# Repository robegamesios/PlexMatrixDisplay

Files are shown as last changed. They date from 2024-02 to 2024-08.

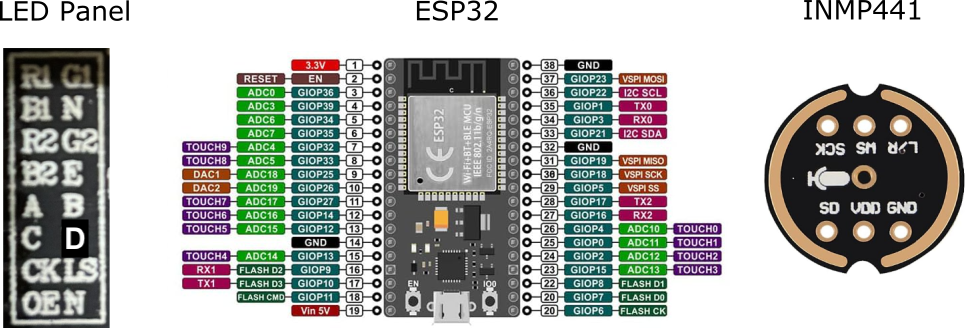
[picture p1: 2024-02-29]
docs/tuneframePinout.png

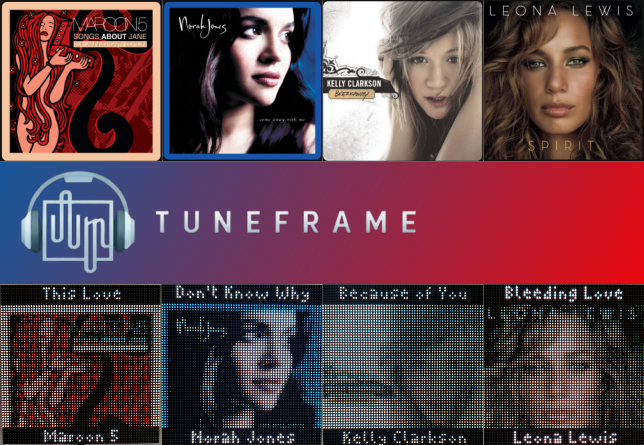
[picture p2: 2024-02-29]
docs/tuneframe.png

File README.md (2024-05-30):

# TUNEFRAME

_**TuneFrame is an ESP32-powered LED matrix panel that serves as a dynamic music visualizer. It syncs captivating LED light patterns with your favorite tunes and displays album art from Spotify and PlexAmp, enhancing your listening experience with vibrant visuals. It also serves as a weather clock station providing current weather information, and as an Animated GIF display to play your favorite GIF art.**_

tuneframe

sddefault



# Video tutorials: 

https://youtu.be/m5aLhCCSwWE?si=qLfko10hiLxpDJDM

https://youtu.be/RzFt6x_XNsM?si=SkvgdLdjnOrtg5Ka

# Hardware

The project will cost less than $30 to build. You can get any of these items somewhere else, but I found Aliexpress to be the cheapest vendor.

1. P3 64 x 64 LED Matrix Panel ($15) - https://www.aliexpress.us/item/3256803863694770.html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
2. INMP441 Omnidirectional Microphone module ($1) - https://www.aliexpress.us/item/3256805923157007.html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
3. ESP32 Wroom 32 Development Board ($3) - https://www.aliexpress.us/item/3256806034074322.html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
4. Dupont cables ($2) - https://www.aliexpress.us/item/3256805941164824.html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
5. 5V 2A power adapter (higher current the better) ($5) - https://www.aliexpress.us/item/3256802434250774.html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
   
# Pinouts

Pinout information can be found here: https://github.com/mrfaptastic/ESP32-HUB75-MatrixPanel-DMA. Below is the connection between the panel and the ESP32. Use female-to-female dupont cables to connect them together.

tuneframePinout

# LED Panel => ESP32

R1 => PIN 25

G1 => PIN 26

B1 => PIN 27

N = GND => Connect to common ground (no. 14 on ESP32 diagram)

R2 => PIN 14

G2 => PIN 12

B2 => PIN 13

E => PIN 18

A => PIN 23

B => PIN 19

C => PIN 5

D => PIN 17

CK => PIN 16

LS (also known as LAT) => 4

OE => PIN 15

N = GND => Connect to common ground (no. 14 on ESP32 diagram)

# INMP441 => ESP32

SD => PIN 32

VDD => 3.3V (no. 1 on ESP32 diagram)

GND => Connect to common ground (no. 14 on ESP32 diagram)

L/R => Connect to common ground (no. 14 on ESP32 diagram)

WS => PIN 2

SCK => PIN 33

# Using a single Power Supply

CAUTION: DO NOT CONNECT THE Vin 5V Pin to the power supply and also connect a micro-usb cable to your computer at the same time, this will fry your ESP32. If you're uploading code using the micro-usb cable, make sure the Vin 5V Pin is not connected to anything.

If you want to use a single power supply for both the LED Panel and the ESP32, you can daisy chain from the 5V power supply and connect the positive (+) terminal to the Vin 5V Pin (no. 19 in the diagram) of the ESP32.

# Software:

# Using Over the Air Update:

1. Download otaDefaultUpdate.ino from here: https://github.com/robegamesios/TUNEFRAME/blob/f9670607f996004907c58c464b867fd6b849f5fa/otaDefaultUpdate/otaDefaultUpdate.ino
2. Download the TuneFrameFirmware.bin from here: https://github.com/robegamesios/TUNEFRAME/blob/f9670607f996004907c58c464b867fd6b849f5fa/binFiles/TuneFrameFirmware.bin
3. Open otaDefaultUpdate.ino, then edit lines 8 and 9 to use your 2.4Ghz wifi credentials.
4. Upload it to your ESP32.
5. Open the Arduino IDE Serial Monitor (top right icon that looks like a Magnifying glass). Notice the wifi IP address.
6. Open your web browser and access the IP address.
7. Leave the User ID and Password blank, and click Login.
8. Choose the file you downloaded from step 2, then click Update.
9. Wait for the upload to finish, it should restart the ESP32 and you see TUNEFRAME at startup.

# Using Visual Studio Code:

1. Fork the TUNEFRAME repo or download the zip file.
2. Import the project in Visual Studio Code using Platform.io. (I'm assuming you are familiar on how to import a platform.io project).

# Get your PlexAmp Auth token:

1. Login to your Plex Media Server using Chrome.
2. Go to your music library, then right click on the page and click "Inspect".
3. Go to the "elements" tab.
4. Search for X-Plex-Token key. Your Auth token will be the characters squeezed between 2 X-Plex-Token keys.
   ```
   X-Plex-Token%3DThisIsYourAuthToken&X-Plex-Token

# Fetching Spotify Refresh Token via Curl command:

You can also get your spotify refresh token using this website: https://robegamesios.github.io/spotify-refresh-token/

1. Download `get-spotify-auth-code.js` from here: https://github.com/robegamesios/TUNEFRAME/blob/926691ebbc9ba7eea4be319e6fc88895b16115f2/misc/get-spotify-auth-code.js
2. Open `get-spotify-auth-code.js` and change lines 8 and 9 to use your Spotify Client ID and Client Secret. Then run it to get the authorization code.
3. Next run this CURL command to get the access token and refresh token:
   ```
   curl -d client_id=[client_id] -d client_secret=[client_secret] -d grant_type=authorization_code -d code=[auth code from step 2] -d redirect_uri=http%3A%2F%2F[esp32 ip address]%2Fcallback/ https://accounts.spotify.com/api/token

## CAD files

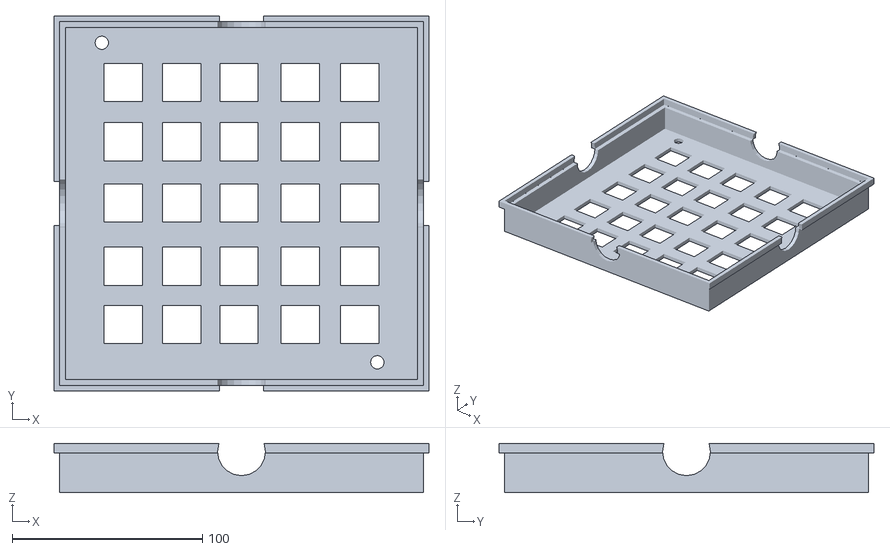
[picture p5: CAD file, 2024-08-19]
stlFiles/p3PanelCase.stl
197.0 x 197.0 x 26.0

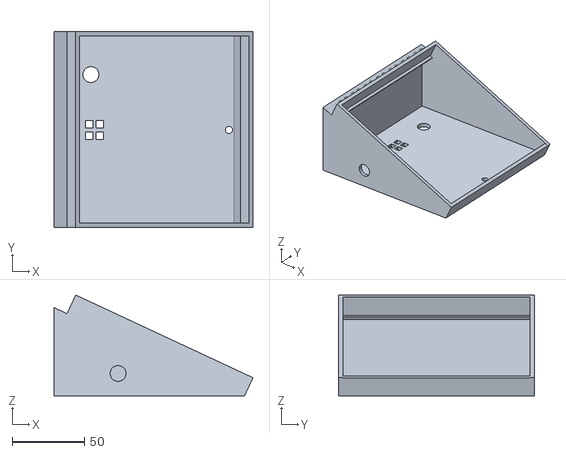
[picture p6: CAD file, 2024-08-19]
stlFiles/p2PanelCase.stl
137.3 x 135.0 x 69.6

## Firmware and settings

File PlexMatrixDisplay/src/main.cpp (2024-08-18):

#define WEATHER_STATION_THEME 90
#define AUDIO_VISUALIZER_THEME 100
#define PLEX_ALBUM_ART_THEME 200
#define SPOTIFY_ALBUM_ART_THEME 201
#define ANIMATED_GIF_THEME 210

// #define DEBUG // UnComment to see debug prints

#define ENABLE_MATRIX_DISPLAY // Comment this to disable matrix display (for debugging purposes when no display is connected)

#include "MatrixDisplay.h"
#include "TFWifiManager.h"
#include "TFNetworking.h"
#include "WeatherClock.h"
#include "PlexAmpLogic.h"
#include "SpotifyLogic.h"
#include "AnimatedGifLogic.h"
#include "jRead.h"

// ******************************************* BEGIN GLOBAL VARS AND COMMON FUNC ******************************
#pragma region GLOBAL_VARS_AND_UTILS

uint8_t selectedTheme;
uint8_t currentlyRunningTheme;
uint8_t panelBrightness;

String scrollingText = "";
String lowerScrollingText = "";
String lastAlbumArtURL = ""; // Variable to store the last downloaded album art URL
bool musicPlayerActive = false;

struct ThemeInfo
{
  String title;
  String filename;

  ThemeInfo(String name, String file)
      : title(name), filename(file) {}
};

ThemeInfo getThemeInfo()
{
  if (selectedTheme == WEATHER_STATION_THEME)
  {
    return ThemeInfo("WEATHER CLOCK", "weatherclock_FW");
  }
  else if (selectedTheme == AUDIO_VISUALIZER_THEME)
  {
    return ThemeInfo("MUSIC VISUALIZER", "musicVisualizer_FW");
  }
  else if (selectedTheme == PLEX_ALBUM_ART_THEME)
  {
    return ThemeInfo("PlEXAMP ART", "plexArt_FW");
  }
  else if (selectedTheme == SPOTIFY_ALBUM_ART_THEME)
  {
    return ThemeInfo("SPOTIFY ART", "spotifyArt_FW");
  }
  else if (selectedTheme == ANIMATED_GIF_THEME)
  {
    return ThemeInfo("ANIMATED GIF ART", "animatedGifArt_FW");
  }

  return ThemeInfo("UNKNOWN THEME", "");
}

void resetAlbumArtVariables()
{
  scrollingText = "";
  lowerScrollingText = "";
  lastAlbumArtURL = "";
}

void deleteAlbumArt()
{
  if (SPIFFS.exists(ALBUM_ART) == true)
  {
    Serial.println("Removing existing image");
    SPIFFS.remove(ALBUM_ART);
  }
}

void displayNoTrackPlaying()
{
#ifdef DEBUG
  Serial.println("No track is currently playing.");
#endif

  musicPlayerActive = false;
  resetAlbumArtVariables();
  clearScreen();
  printCenter("NO TRACK IS", 20, myPURPLE);
  printCenter("CURRENTLY", 30, myPURPLE);
  printCenter("PLAYING", 40, myPURPLE);
}

void displayCheckWeatherCredentials()
{
#ifdef DEBUG
  Serial.println("Check Weather credentials");
#endif

  resetAlbumArtVariables();
  clearScreen();
  printCenter("CHECK WEATHER", 25, myRED);
  printCenter("CREDENTIALS", 35, myRED);
}

void displayCheckPlexAmpCredentials()
{
#ifdef DEBUG
  Serial.println("Check PlexAmp credentials");
#endif

  resetAlbumArtVariables();
  clearScreen();
  printCenter("CHECK PLEXAMP", 25, myRED);
  printCenter("CREDENTIALS", 35, myRED);
}

void displayCheckSpotifyCredentials()
{
#ifdef DEBUG
  Serial.println("Check Spotify credentials");
#endif

  resetAlbumArtVariables();
  clearScreen();
  printCenter("CHECK SPOTIFY", 25, myRED);
  printCenter("CREDENTIALS", 35, myRED);
}

void displayMusicPaused()
{
  String musicPaused = "Music Paused";
  if (lowerScrollingText != musicPaused)
  {
    lowerScrollingText = musicPaused;
  }
}

void displayFailureReloadGifArt()
{
#ifdef DEBUG
  Serial.println("cannot open gif file");
#endif

  printCenter("FAILURE..", 15, myRED);
  printCenter("TRY LOADING", 25, myRED);
  printCenter("GIF ART AGAIN", 35, myRED);
  printCenter("FROM BROWSER", 45, myRED);
}

void restartDevice()
{
  clearScreen();
  printCenter("RESTARTING..", 30);
  delay(1000);
  ESP.restart();
}

void resetWifi()
{
  printCenter("RESETTING WiFi..", 30);
  wifiManager.resetSettings();
}

#pragma endregion
// ******************************************* END GLOBAL VARS AND COMMON FUNC ********************************

// ******************************************* BEGIN PREFERENCES **********************************************
#pragma region PREFERENCES

#include <Preferences.h>

Preferences preferences;
const char *PREF_SELECTED_THEME = "selectedTheme";
const char *PREF_AV_PATTERN = "avPattern";
const char *PREF_GIF_ART_URL = "gifArtUrl";
const char *PREF_WEATHER_STATION_CREDENTIALS = "weatherStationCredentials";
const char *PREF_PLEX_CREDENTIALS = "plexCredentials";
const char *PREF_SPOTIFY_CREDENTIALS = "spotifyCredentials";
const char *PREF_DISPLAY_GIF_TIME_AND_WEATHER = "displayGifTimeAndWeather";
const char *PREF_PANEL_BRIGHTNESS = "panelBrightness";

void savePreferences()
{
  preferences.putUInt(PREF_SELECTED_THEME, selectedTheme);
  preferences.putUInt(PREF_PANEL_BRIGHTNESS, panelBrightness);
}

void loadPreferences()
{
  selectedTheme = preferences.getUInt(PREF_SELECTED_THEME, AUDIO_VISUALIZER_THEME);
  panelBrightness = preferences.getUInt(PREF_PANEL_BRIGHTNESS, 128);
}

#pragma endregion
// ******************************************* END PREFERENCES ************************************************

// ******************************************* BEGIN CLOCK ****************************************************
#pragma region CLOCK

#if defined(WEATHERCLOCK_MODE) || defined(ANIMATEDGIF_MODE)

unsigned long lastWeatherUpdateTime = 0;
unsigned long lastClockUpdateTime = 0;
const unsigned long weatherUpdateInterval = 600000; // 10 minutes
const unsigned long clockUpdateInterval = 1000;     // 1 second

bool displayGifTimeAndWeather = false;

void getDateAndTime()
{
  String localTime = getLocalTimeAndDate();
#ifdef DEBUG
  Serial.println("current time = " + localTime);
#endif
  scrollingText = localTime;
}

#endif

#pragma endregion
// ******************************************* END CLOCK ******************************************************

// ******************************************* BEGIN WEATHER **************************************************
#pragma region WEATHER

#ifdef WEATHERCLOCK_MODE

#include "weatherIcons.h"

// Draw one of the available weather icons in the specified space
void drawWeatherIcon(int startx, int starty, int width, int height, std::string icon, bool enlarged)
{
  // Perform switch-case based on the entire string
  if (icon == "01d")
  {
    drawBitmap(startx, starty, width, height, sun_24x24, enlarged);
  }
  else if (icon == "01n")
  {
    drawBitmap(startx, starty, width, height, moon_24x24, enlarged);
  }
  else if (icon == "02d")
  {
    drawBitmap(startx, starty, width, height, fewClouds_24x24, enlarged);
  }
  else if (icon == "02n")
  {
    drawBitmap(startx, starty, width, height, fewCloudsNight_24x24, enlarged);
  }
  else if (icon == "03d" || icon == "03n")
  {
    drawBitmap(startx, starty, 24, 24, scatteredClouds_24x24, enlarged);
  }
  else if (icon == "04d" || icon == "04n")
  {
    drawBitmap(startx, starty, 24, 24, brokenClouds_24x24, enlarged);
  }
  else if (icon == "09d")
  {
    drawBitmap(startx, starty, width, height, showers_24x24, enlarged);
  }
  else if (icon == "09n")
  {
    drawBitmap(startx, starty, width, height, showersNight_24x24, enlarged);
  }
  else if (icon == "10d" || icon == "10n")
  {
    drawBitmap(startx, starty, width, height, rain_24x24, enlarged);
  }
  else if (icon == "11d" || icon == "11n")
  {
    drawBitmap(startx, starty, width, height, thunderstorm_24x24, enlarged);
  }
  else if (icon == "13d" || icon == "13n")
  {
    drawBitmap(startx, starty, width, height, snow_24x24, enlarged);
  }
  else if (icon == "50d")
  {
    drawBitmap(startx, starty, width, height, mist_24x24, enlarged);
  }
}

void printTemperature(std::string icon, const char *buf, int x, int y, uint16_t textColor = myWHITE, GFXfont font = Picopixel)
{
  int padding = 2;
  int degreeSymbolWidth = 3;
  int iconWidth = 24;
  int iconHeight = 24;

  int16_t x1, y1;
  uint16_t w, h;
  dma_display->setFont(&font);
  dma_display->getTextBounds(buf, 0, y, &x1, &y1, &w, &h);

  int iconStartX = (PANEL_WIDTH - iconWidth - padding - w - degreeSymbolWidth) / 2;
  int iconStartY = y - iconHeight + (iconHeight - h) / 2;

  // Clear the screen
  displayRect(0, iconStartY, PANEL_WIDTH, iconHeight, myBLACK); // clear full width of screen and height of icon

  drawWeatherIcon(iconStartX, iconStartY, iconWidth, iconHeight, icon, false);

  int textStartX = iconStartX + iconWidth + padding;
  dma_display->setCursor(textStartX, y);
  dma_display->setTextColor(textColor);
  dma_display->print(buf);

  // Calculate the position for the circle
  int circleX = textStartX + w + padding; // Add some padding between text and circle
  int circleY = y - h;                    // Center the circle vertically

  dma_display->drawCircle(circleX, circleY, 1, textColor);
}

void displayWeatherData(WeatherData data)
{
  printCenter(data.cityName.c_str(), 13, myORANGE);

  printTemperature(data.weatherIcon, data.temperature.c_str(), 22, 35, myGREEN, FreeSerifBold9pt7b);

  printLeft(data.feelsLike.c_str(), 5, 47, myPURPLE);
  printLeft(data.humidity.c_str(), 5, 54, myGOLD);

  printLeft(data.tempMin.c_str(), 40, 47, myCYAN);
  printLeft(data.tempMax.c_str(), 40, 54, myRED);

  lowerScrollingText = data.extraInfo.c_str();

  delay(500);
  getDateAndTime();
}

#endif

#if defined(WEATHERCLOCK_MODE) || defined(ANIMATEDGIF_MODE)

void getWeatherInfo()
{
  String city = String(weatherCityName);
  city.replace("%20", "+"); // change space to + for cities with more than 1 word.
  String countryCode = String(weatherCountryCode);
  String apiKey = String(weatherApikey);
  String unit = getWeatherUnit();

  String endpoint = "http://api.openweathermap.org/data/2.5/weather?q=" + city + "," + countryCode + "&APPID=" + apiKey + "&units=" + unit;

#ifdef DEBUG
  Serial.println("weather endpoint = " + endpoint);
#endif

  HTTPClient http;
  http.begin(endpoint);

  int httpCode = http.GET();

  if (httpCode == HTTP_CODE_OK)
  {
    String httpResponse = http.getString();
#ifdef DEBUG
    Serial.println("http response: " + httpResponse);
#endif

    const char *jsonCString = httpResponse.c_str();
    WeatherData data = processWeatherJson(jsonCString);

#ifdef WEATHERCLOCK_MODE
#ifdef ENABLE_MATRIX_DISPLAY
    displayWeatherData(data);
#else
    String fullInfo = data.fullInfo.c_str();
    Serial.println("Weather Data = " + fullInfo);
#endif

#elif ANIMATEDGIF_MODE
    lowerScrollingText = data.fullInfo.c_str();
#endif
  }
  else
  {
    Serial.print("Error code: ");
    Serial.println(httpCode);
  }

  http.end();
}

void fetchWeatherAndTime()
{
  unsigned long currentMillis = millis();

  if (currentMillis - lastClockUpdateTime >= clockUpdateInterval)
  {
    lastClockUpdateTime = currentMillis;
    getDateAndTime();
  }

  if (currentMillis - lastWeatherUpdateTime >= weatherUpdateInterval)
  {
    lastWeatherUpdateTime = currentMillis;
    getWeatherInfo();
  }
  printScrolling(scrollingText.c_str(), 5, myBLUE);
  printScrolling2(lowerScrollingText.c_str(), 62, myBLUE);
}

#endif

#pragma endregion
// ******************************************* END WEATHER ****************************************************

// ******************************************* BEGIN PLEX ALBUM ART *******************************************
#pragma region PLEX_ALBUM_ART

#ifdef PLEXAMP_MODE

void downloadPlexAlbumArt(String relativeUrl, String trackTitle, String artistName)
{
  String imageUrl = "http://" + String(plexServerIp) + ":" + String(plexServerPort) + "/photo/:/transcode?width=48&height=48&url=" + relativeUrl;
  String headerKey = "X-Plex-Token";
  String headerValue = plexServerToken;

  // Send GET request to the image URL
  httpGet(imageUrl, headerKey, headerValue, [&](int httpCode, const String &response)
          {
    if (httpCode == HTTP_CODE_OK) {
      // Successfully downloaded the image, now save it to SPIFFS
      File file = SPIFFS.open(ALBUM_ART, FILE_WRITE);
      if (!file) {
        Serial.println("Failed to create file");
        return;
      }
      file.print(response);
      file.close();
      // Check if the file exists
      if (SPIFFS.exists(ALBUM_ART)) {
        Serial.println("Image downloaded and saved successfully");
        // Update the last downloaded album art URL using the captured parameter
        clearScreen();
        lastAlbumArtURL = imageUrl;
        drawImagefromFile(ALBUM_ART, 8);
        scrollingText = trackTitle;
        lowerScrollingText = artistName;
      } else {
        Serial.println("Failed to save image to SPIFFS");
      }
    } else {
      Serial.print("Failed to download image. HTTP error code: ");
      Serial.println(httpCode);
    } });
}

void getPlexCurrentTrack()
{
  String apiUrl = "http://" + String(plexServerIp) + ":" + String(plexServerPort) + "/status/sessions";
  String headerKey = "X-Plex-Token";
  String headerValue = String(plexServerToken);

  httpGet(apiUrl, headerKey, headerValue, [](int httpCode, const String &response)
          {
#ifdef DEBUG
            Serial.println("plex http code: " + httpCode);
#endif
    if (httpCode == HTTP_CODE_OK) {
      PlexData data = processPlexResponse(response);
            // Check if the current album art URL is different from the last one
            String coverArtUrl = data.artUrl;
            String trackTitle = data.trackTitle;
            String artistName = data.artistName;

            if (artistName == "")
            {
              displayNoTrackPlaying();
            }
            if (artistName == "paused")
            {
                displayMusicPaused();
            }
            else if (coverArtUrl != lastAlbumArtURL)
            {
              // Delete old cover art
              deleteAlbumArt();

              // Download and save the thumbnail image
              downloadPlexAlbumArt(coverArtUrl, trackTitle, artistName);
              lastAlbumArtURL = coverArtUrl; // Update the last downloaded album art URL
            }
            else
            {
#ifdef DEBUG
              Serial.println("Album art hasn't changed. Skipping download.");
#endif

              // Trigger scrolling song title
              scrollingText = trackTitle;
              lowerScrollingText = artistName;
            }

    } else {
      displayNoTrackPlaying();
    } });
}

#endif

#pragma endregion
// ******************************************* END PLEX ALBUM ART *********************************************

// ******************************************* BEGIN SPOTIFY ALBUM ART ****************************************
#pragma region SPOTIFY_ALBUM_ART

#ifdef SPOTIFY_MODE

void getSpotifyRefreshToken()
{
  Serial.println("***********Fetching Refresh Token*********");
  printCenter("REFRESHING", 25, myCYAN);
  printCenter("ACCESS TOKEN", 35, myCYAN);

  String response = fetchSpotifyRefreshToken();

  if (response.length() > 0)
  {
    // parse the refreshed access token
    const char *pJson = response.c_str();
    jRead_string(pJson, "{'access_token'", refreshedAccessToken, 256);
    clearScreen();
  }
  else
  {
    Serial.println("Unable to find the end of refreshed access token");
    displayCheckSpotifyCredentials();
  }
}

void downloadSpotifyAlbumArt(String imageUrl)
{
  if (imageUrl == lastAlbumArtURL)
  {
#ifdef DEBUG
    Serial.println("Album art hasn't changed. Skipping download");
#endif
    return;
  }
  deleteAlbumArt();

  // Send GET request to the image URL
  httpGet(imageUrl, "", "", [&](int httpCode, const String &response)
          {
    if (httpCode == HTTP_CODE_OK) {
      // Successfully downloaded the image, now save it to SPIFFS
      File file = SPIFFS.open(ALBUM_ART, FILE_WRITE);
      if (!file) {
        Serial.println("Failed to create file");
        return;
      }
      file.print(response);
      file.close();
      // Check if the file exists
      if (SPIFFS.exists(ALBUM_ART)) {
        Serial.println("Image downloaded and saved successfully");
        // Update the last downloaded album art URL using the captured parameter
        lastAlbumArtURL = imageUrl;
        drawImagefromFile(ALBUM_ART, 0);
      } else {
        Serial.println("Failed to save image to SPIFFS");
      }
    } else {
      Serial.print("Failed to download image. HTTP error code: ");
      Serial.println(httpCode);
    } });
}

void processSpotifyJson(const char *pJson)
{
  char str[128]; // general use string buffer
  jRead_string(pJson, "{'item'{'name'", str, 128);
  String trackTitle = str;

  jRead_string(pJson, "{'item'{'album'{'artists'[{'name'", str, 128);
  String artistName = str;

  jRead_string(pJson, "{'item'{'album'{'images'[2{'url'", str, 128);
  String albumArtUrl = str;

  jRead_string(pJson, "{'is_playing'", str, 128);
  String isPlaying = str;

#ifdef DEBUG
  Serial.println("Spotify track title: " + trackTitle);
  Serial.println("Spotify artist name: " + artistName);
  Serial.println("Spotify album Art Url: " + albumArtUrl);
  Serial.println("Spotify is playing: " + isPlaying);
#endif

  if (isPlaying != "true")
  {
    displayMusicPaused();
    return;
  }

  scrollingText = trackTitle;
  lowerScrollingText = artistName;

  if (albumArtUrl != lastAlbumArtURL)
  {
    spotifyAlbumArtUrl = albumArtUrl;
  }
}

void getSpotifyCurrentTrack()
{
  // Your API endpoint
  String endpoint = "https://api.spotify.com/v1/me/player/currently-playing";

  // Authorization header
  String headerKey = "Authorization";
  String headerValue = "Bearer " + String(refreshedAccessToken);

  httpGet(endpoint, headerKey, headerValue, [](int httpCode, const String &response)
          {
#ifdef DEBUG
    Serial.println("http code: " + httpCode);
#endif

    if (httpCode == HTTP_CODE_UNAUTHORIZED) {
      Serial.println("***** Access token expired");
      restartDevice();
    } else if (httpCode == HTTP_CODE_NO_CONTENT) {
      displayNoTrackPlaying();
    } else if (httpCode == HTTP_CODE_OK) {
      musicPlayerActive = true;
      // Convert to const char*
      const char *jsonCString = response.c_str();
      processSpotifyJson(jsonCString);

    } else {
      displayCheckSpotifyCredentials();
    } });
}

#endif

#pragma endregion
// ******************************************* END SPOTIFY ALBUM ART ******************************************

// ******************************************* BEGIN AUDIO VISUALIZER *****************************************
#pragma region AUDIO_VISUALIZER

#ifdef AV_MODE

#include <FastLED_NeoMatrix.h>
#include <arduinoFFT.h>
#include "I2SPLUGIN.h"
#include <math.h>
#include <ESP32-HUB75-MatrixPanel-I2S-DMA.h>
#include "FFT.h"
#include "Settings.h"
#include "PatternsHUB75.h"

#define up 1
#define down 0
int PeakDirection = 0;

long LastDoNothingTime = 0; // only needed for screensaver
int DemoModeMem = 0;        // to remember what mode we are in when going to demo, in order to restore it after wake up
bool AutoModeMem = false;   // same story
bool DemoFlag = false;      // we need to know if demo mode was manually selected or auto engadged.

char LCDPrintBuf[30];

// BucketFrequency
//
// Return the frequency corresponding to the Nth sample bucket.  Skips the first two
// buckets which are overall amplitude and something else.

int BucketFrequency(int iBucket)
{
  if (iBucket <= 1)
    return 0;
  int iOffset = iBucket - 2;
  return iOffset * (samplingFrequency / 2) / (SAMPLEBLOCK / 2);
}

void DrawVUPixels(int i, int yVU, int fadeBy = 0)
{
  CRGB VUC;
  if (i > (PANE_WIDTH / 3))
  {
    VUC.r = 255;
    VUC.g = 0;
    VUC.b = 0;
  }
  else if (i > (PANE_WIDTH / 5))
  {
    VUC.r = 255;
    VUC.g = 255;
    VUC.b = 0;
  }
  else
  { // green
    VUC.r = 0;
    VUC.g = 255;
    VUC.b = 0;
  }

  int xHalf = PANE_WIDTH / 2;
  dma_display->drawPixelRGB888(xHalf - i - 2, yVU, VUC.r, VUC.g, VUC.b);     // left side of screen line 0
  dma_display->drawPixelRGB888(xHalf - i - 2, yVU + 1, VUC.r, VUC.g, VUC.b); // left side of screen line 1
  dma_display->drawPixelRGB888(xHalf + i + 1, yVU, VUC.r, VUC.g, VUC.b);     // right side of screen line 0
  dma_display->drawPixelRGB888(xHalf + i + 1, yVU + 1, VUC.r, VUC.g, VUC.b); // right side of screen line 1
}
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
void loop()
{
  if (isConnected())
  {
    handleHttpRequest();

#if defined(WEATHERCLOCK_MODE)
    fetchWeatherAndTime();
#endif

#ifdef AV_MODE
    loopAudioVisualizer();
#endif

#ifdef PLEXAMP_MODE
    unsigned long currentMillis = millis();

    if (currentMillis - lastAlbumArtUpdateTime >= albumArtUpdateInterval && !isTextScrolling && !isTextScrolling2) //! isTextScrolling && !isTextScrolling2 is just a work around for scrolling text to not pause when polling is done
    {
      lastAlbumArtUpdateTime = currentMillis;
      getPlexCurrentTrack();
    }
    printScrolling(scrollingText.c_str(), 5, myBLUE);
    printScrolling2(lowerScrollingText.c_str(), 62, myBLUE);
#endif

#ifdef SPOTIFY_MODE
    unsigned long currentMillis = millis();

    if (currentMillis - lastAlbumArtUpdateTime >= albumArtUpdateInterval && !isTextScrolling && !isTextScrolling2) //! isTextScrolling && !isTextScrolling2 is just a work around for scrolling text to not pause when polling is done
    {
      lastAlbumArtUpdateTime = currentMillis;
      getSpotifyCurrentTrack();

      if (spotifyAlbumArtUrl.length() > 0 && musicPlayerActive)
      {
        downloadSpotifyAlbumArt(spotifyAlbumArtUrl);
      }
    }
    printScrolling(scrollingText.c_str(), 5, myBLUE);
    printScrolling2(lowerScrollingText.c_str(), 62, myBLUE);
#endif

#ifdef ANIMATEDGIF_MODE
    if (displayGifTimeAndWeather)
    {
      fetchWeatherAndTime();
    }
    showGIF();
#endif
  }
}

#pragma endregion
// ******************************************* END MAIN *******************************************************

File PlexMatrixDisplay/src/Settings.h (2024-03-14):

 
 /********************************************************************************************************************************************************
 *                                                                                                                                                       *
 *  Project:         FFT Spectrum Analyzer                                                                                                               *
 *  Target Platform: ESP32                                                                                                                               *
 *                                                                                                                                                       * 
 *  Version: 1.0                                                                                                                                         *
 *  Hardware setup: See github                                                                                                                           *
 *  Spectrum analyses done with analog chips MSGEQ7                                                                                                      *
 *                                                                                                                                                       * 
 *  Mark Donners                                                                                                                                         *
 *  The Electronic Engineer                                                                                                                              *
 *  Website:   www.theelectronicengineer.nl                                                                                                              *
 *  facebook:  https://www.facebook.com/TheelectronicEngineer                                                                                            *
 *  youtube:   https://www.youtube.com/channel/UCm5wy-2RoXGjG2F9wpDFF3w                                                                                  *
 *  github:    https://github.com/donnersm                                                                                                               *
 *                                                                                                                                                       *  
 ********************************************************************************************************************************************************/
 

#pragma once
#define DEBUG_BUFFER_SIZE   100                     // Debug buffer size

//Options Change to your likings
#define Fallingspeed        5                       // Falling down factor that effects the speed of falling tiles
#define LogoBoot            1                       // Show logo on boot when set to 1, only works in combination with HUB75
int Peakdelay =             60;                     // Delay before peak falls down to stack. Overruled by PEAKDEALY Potmeter
#define GAIN_DAMPEN         2                       // Higher values cause auto gain to react more slowly
int secToChangePattern = 60;                      // number of seconds that pattern changes when auto change mode is enabled
#define MAX_VU              5000                    // How high our VU could max out at.  Arbitarily tuned.
int buttonPushCounter =     0;                      // This number defines what pattern to start after boot (0 to 12)
bool autoChangePatterns =   true;                  // After boot, the pattern will not change automatically. 
int NoiseTresshold =        1500;                   // this will effect the upper bands most.
#define DemoAfterSec        6000                    // if there is no input signal during this number of milli seconds, the unit will go to demo mode
#define DemoTreshold        500                     // this defines the treshold that will get the unit out of demo mode
#define BRIGHTNESSMAX       255                     // Max brightness of the leds...carefull...to bright might draw to much amps!
int BRIGHTNESSMARK= 50;                            // Default brightnetss, however, overruled by the Brightness potmeter
int BRIGHTNESSMIN = 20;                              // Min brightness

//Controls  //don't change unless you are using your own hardware design
#define BRIGHTNESSPOT 2 
#define PEAKDELAYPOT  4
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

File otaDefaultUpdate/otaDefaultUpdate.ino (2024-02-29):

#include <WiFi.h>
#include <WiFiClient.h>
#include <WebServer.h>
#include <ESPmDNS.h>
#include <Update.h>

const char* host = "esp32";
const char* ssid = "SSID";
const char* password = "password";

WebServer server(80);

/* Style */
String style =
"<style>#file-input,input{width:100%;height:44px;border-radius:4px;margin:10px auto;font-size:15px}"
"input{background:#f1f1f1;border:0;padding:0 15px}body{background:#3498db;font-family:sans-serif;font-size:14px;color:#777}"
"#file-input{padding:0;border:1px solid #ddd;line-height:44px;text-align:left;display:block;cursor:pointer}"
"#bar,#prgbar{background-color:#f1f1f1;border-radius:10px}#bar{background-color:#3498db;width:0%;height:10px}"
"form{background:#fff;max-width:258px;margin:75px auto;padding:30px;border-radius:5px;text-align:center}"
".btn{background:#3498db;color:#fff;cursor:pointer}</style>";

/* Login page */
String loginIndex = 
"<form name=loginForm>"
"<h1>ESP32 Login</h1>"
"<input name=userid placeholder='User ID'> "
"<input name=pwd placeholder=Password type=Password> "
"<input type=submit onclick=check(this.form) class=btn value=Login></form>"
"<script>"
"function check(form) {"
"if(form.userid.value=='' && form.pwd.value=='')"
"{window.open('/serverIndex')}"
"else"
"{alert('Error Password or Username')}"
"}"
"</script>" + style;
 
/* Server Index Page */
String serverIndex = 
"<script src='https://ajax.googleapis.com/ajax/libs/jquery/3.2.1/jquery.min.js'></script>"
"<form method='POST' action='#' enctype='multipart/form-data' id='upload_form'>"
"<input type='file' name='update' id='file' onchange='sub(this)' style=display:none>"
"<label id='file-input' for='file'>   Choose file...</label>"
"<input type='submit' class=btn value='Update'>"
"<br><br>"
"<div id='prg'></div>"
"<br><div id='prgbar'><div id='bar'></div></div><br></form>"
"<script>"
"function sub(obj){"
"var fileName = obj.value.split('\\\\');"
"document.getElementById('file-input').innerHTML = '   '+ fileName[fileName.length-1];"
"};"
"$('form').submit(function(e){"
"e.preventDefault();"
"var form = $('#upload_form')[0];"
"var data = new FormData(form);"
"$.ajax({"
"url: '/update',"
"type: 'POST',"
"data: data,"
"contentType: false,"
"processData:false,"
"xhr: function() {"
"var xhr = new window.XMLHttpRequest();"
"xhr.upload.addEventListener('progress', function(evt) {"
"if (evt.lengthComputable) {"
"var per = evt.loaded / evt.total;"
"$('#prg').html('progress: ' + Math.round(per*100) + '%');"
"$('#bar').css('width',Math.round(per*100) + '%');"
"}"
"}, false);"
"return xhr;"
"},"
"success:function(d, s) {"
"console.log('success!') "
"},"
"error: function (a, b, c) {"
"}"
"});"
"});"
"</script>" + style;

/* setup function */
void setup(void) {
  Serial.begin(115200);

  Serial.print("\nDefault ESP32 MAC Address: ");
  Serial.println(WiFi.macAddress());

  // Connect to WiFi network
  WiFi.begin(ssid, password);
  Serial.println("");

  // Wait for connection
  while (WiFi.status() != WL_CONNECTED) {
    delay(500);
    Serial.print(".");
  }
  Serial.println("");
  Serial.print("Connected to ");
  Serial.println(ssid);
  Serial.print("IP address: ");
  Serial.println(WiFi.localIP());

  /*use mdns for host name resolution*/
  if (!MDNS.begin(host)) { //http://esp32.local
    Serial.println("Error setting up MDNS responder!");
    while (1) {
      delay(1000);
    }
  }
  Serial.println("mDNS responder started");
  /*return index page which is stored in serverIndex */
  server.on("/", HTTP_GET, []() {
    server.sendHeader("Connection", "close");
    server.send(200, "text/html", loginIndex);
  });
  server.on("/serverIndex", HTTP_GET, []() {
    server.sendHeader("Connection", "close");
    server.send(200, "text/html", serverIndex);
  });
  /*handling uploading firmware file */
  server.on("/update", HTTP_POST, []() {
    server.sendHeader("Connection", "close");
    server.send(200, "text/plain", (Update.hasError()) ? "FAIL" : "OK");
    ESP.restart();
  }, []() {
    HTTPUpload& upload = server.upload();
    if (upload.status == UPLOAD_FILE_START) {
      Serial.printf("Update: %s\n", upload.filename.c_str());
      if (!Update.begin(UPDATE_SIZE_UNKNOWN)) { //start with max available size
        Update.printError(Serial);
      }
    } else if (upload.status == UPLOAD_FILE_WRITE) {
      /* flashing firmware to ESP*/
      if (Update.write(upload.buf, upload.currentSize) != upload.currentSize) {
        Update.printError(Serial);
      }
    } else if (upload.status == UPLOAD_FILE_END) {
      if (Update.end(true)) { //true to set the size to the current progress
        Serial.printf("Update Success: %u\nRebooting...\n", upload.totalSize);
      } else {
        Update.printError(Serial);
      }
    }
  });
  server.begin();
}

void loop(void) {
  server.handleClient();
  delay(1);
}

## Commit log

2024-03-08 Feature/fix screensaver (#9)
    fix screensaver
    [main.cpp]
2024-03-15 fix scrolling text (#11)
    [MatrixDisplay.h, main.cpp]
2024-08-19 added stl files
    [p2PanelCase.stl, p3PanelCase.stl]
